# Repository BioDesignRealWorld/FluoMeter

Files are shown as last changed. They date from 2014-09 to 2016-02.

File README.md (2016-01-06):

FluoMeter
=========

This repository contains all technical files (CAD drawings, PCB files,
firmware) to reproduce a quantitative fluorescence measurement device. This
device was created by the [BioDesign for the Real-World](http://biodesign.cc)
project to be used together with a bio-reporter for arsenic or other heavy
metal detection.

* [Chronology and principle of the device](http://wiki.biodesign.cc/wiki/Chronology_of_the_prototypes)
* [Build the FluoMeter](http://wiki.biodesign.cc/wiki/Arsenic-Prototype-4-0)
* [BioDesign wiki](http://wiki.biodesign.cc)
* [BioDesign blog](http://biodesign.cc)
* [Arsenic biosensors literature](http://www.unil.ch/arsenicsensors/en/home/menuguid/literature.html)

What is the BioDesign for the Real-World project ?
--------------------------------------------------

BIO-DESIGN for the REAL WORLD is a transdisciplinary and collaborative research
project to define, build, and field-test prototypes that require the
integration of wetware, hardware, and software to visualise and address real
world water problems.



The project is a partnership between (Art)ScienceBLR with design students from
the Srishti School of Art, Design & Technology, (Bangalore, India) the
Lifepatch citizen initiative in art, science and technology (Yogyakarta,
Indonesia), and students at the School of Life Sciences at EPFL (Lausanne,
Switzerland, and housed in Hackuarium). We collaborate closely with
National Centre for Biological Sciences (NCBS, Bangalore India),
and Universitas Gadjah Mada (Yogyakarta, Indonesia).

We follow the open process – CC BY-SA 3.0 and a do-it-yourself (DIY) and do-it-with-others DIWO) approach. Our documentation can be found on the project wiki and we share our code and designs on github. Be sure to check out our videos and links.

BioDesign started as an idea in the hackterialab 2011 in Romainmôtier in Switzerland. We are part of the hackteria network. Check out Hackteria’s wiki page for other DIYBIO projects and designs.

The project was launched with support by the CoDEV SEED grant from EPFL (2.2013-12.2014).





Contributors
------------

* Sachiko Hirosue
* Robin Scheibler
* Emilie Mussard
* Romain Equey
* Jasmina Rubattel
* Nicolas Krischer
* Bastien Orset
* Falco Enzler
* Thomas Vetterli
* Dounia Droubi
* Marie Duc
* Colombine Verzat
* Marie Willemin
* Mathilde Vidal

Collaborators at large
----------------------

* [Lifepatch](http://lifepatch.org/)
* [(Art)ScienceBLR](http://artscienceblr.org/)
* [Lab of environmental and evolutionary microbiology (UNIL)](http://www.unil.ch/dmf/en/home/menuinst/research-units/van-der-meer.html)
* [Microsystems laboratory 4 (EPFL)](http://lmis4.epfl.ch/)

License
-------

(c) 2015 Biodesign for the Real-World

This is an open-source hardware project shared under the CC-BY-SA. You can
modify, remix, reuse and redistribute this work as long as it is under the same
conditions. See the terms of the license below for more details.

<br /><span xmlns:dct="http://purl.org/dc/terms/" property="dct:title">FluoMeter</span> by <a xmlns:cc="http://creativecommons.org/ns#" href="http://biodesign.cc" property="cc:attributionName" rel="cc:attributionURL">BioDesign for the Real-World</a> is licensed under a <a rel="license" href="http://creativecommons.org/licenses/by-sa/4.0/">Creative Commons Attribution-ShareAlike 4.0 International License</a>.<br />Based on a work at <a xmlns:dct="http://purl.org/dc/terms/" href="https://github.com/BioDesignRealWorld/FluoMeter" rel="dct:source">https://github.com/BioDesignRealWorld/FluoMeter</a>.

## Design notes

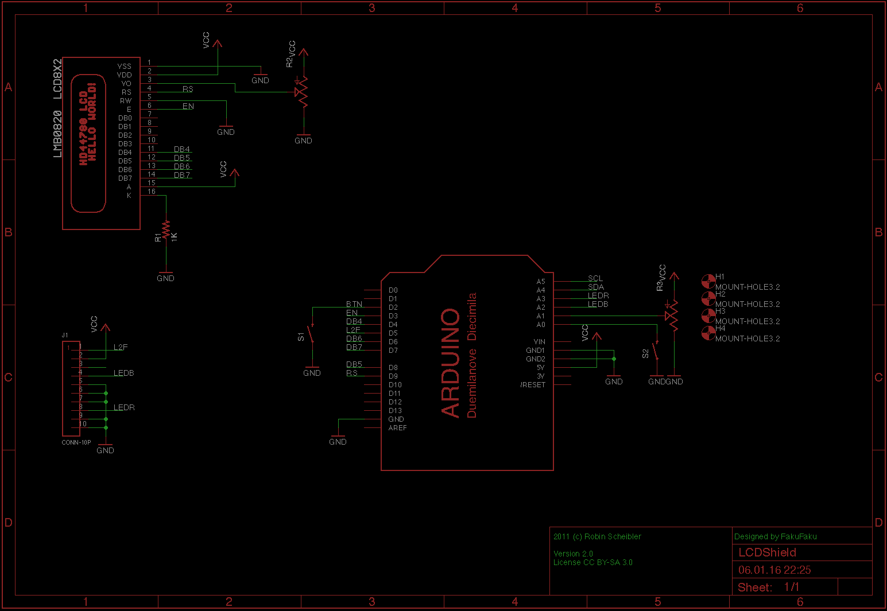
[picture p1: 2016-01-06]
PCB/LCDShield.png

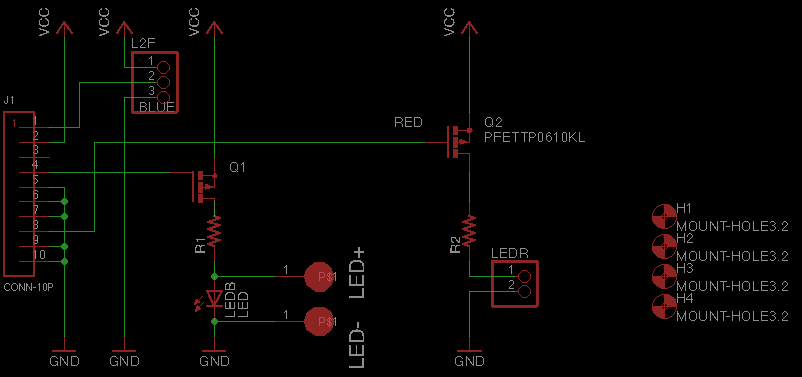
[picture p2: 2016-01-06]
PCB/Proto4_main_board.png

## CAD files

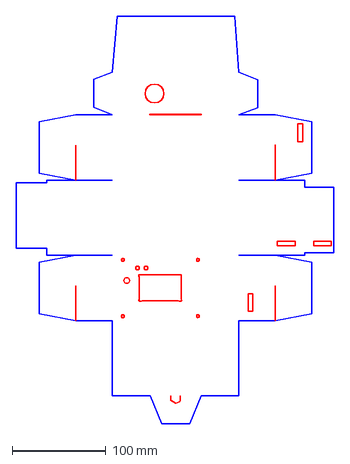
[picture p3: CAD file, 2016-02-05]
CAD/Winter School laser cut box template.dxf
338.6 x 435.0 mm

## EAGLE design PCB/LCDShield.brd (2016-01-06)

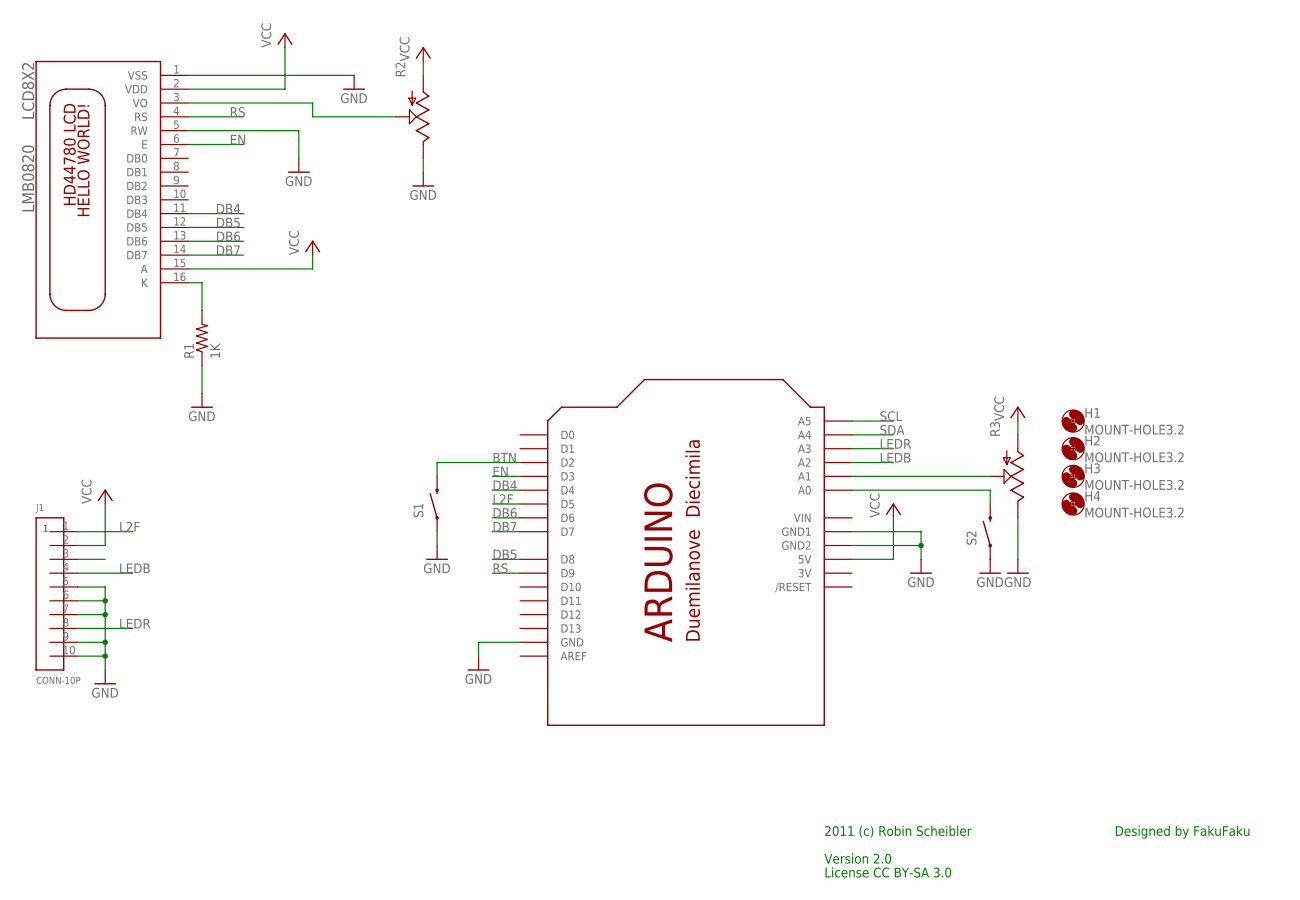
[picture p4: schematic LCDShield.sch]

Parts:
H1, H2, H3, H4: MOUNT-HOLE3.2; 3,2
J1: CONN-10P; MICROMATCH-10P-SMD
LCD8X2: LMB0820
R1: 1K; 0207/10
R2: POTTRIM; TRIM_POT
R3: POT; ALPS_POT
S1, S2: SWITCH-MOMENTARY-2PTH; TACTILE-PTH
SHIELD: ARDUINOSHIELD-PINS; ARDUINO-PINS

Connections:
3V: SHIELD.3V
BTN: S1.3 (2), SHIELD.D2
CON3: J1.3
DB4: LCD8X2.11 (DB4), SHIELD.D4
DB5: LCD8X2.12 (DB5), SHIELD.D8
DB6: LCD8X2.13 (DB6), SHIELD.D6
DB7: LCD8X2.14 (DB7), SHIELD.D7
EN: LCD8X2.6 (E), SHIELD.D3
GND: J1.5, J1.6, J1.7, J1.9, J1.10, LCD8X2.1 (VSS), LCD8X2.5 (RW), R1.1, R2.2 (E), R3.P$1 (E), S1.1, S2.1, SHIELD.GND, SHIELD.GND1, SHIELD.GND2
L2F: J1.1, SHIELD.D5
LEDB: J1.4, SHIELD.A2
LEDR: J1.8, SHIELD.A3
unnamed: LCD8X2.16 (K), R1.2
unnamed: LCD8X2.3 (VO), R2.1 (S)
unnamed: S2.3 (2), SHIELD.A0
unnamed: R3.P$2 (S), SHIELD.A1
RS: LCD8X2.4 (RS), SHIELD.D9
SCL: SHIELD.A5
SDA: SHIELD.A4
VCC: J1.2, LCD8X2.2 (VDD), LCD8X2.15 (A), R2.3 (A), R3.P$3 (A), SHIELD.5V
VIN: SHIELD.VIN

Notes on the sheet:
Version 2.0
License CC BY-SA 3.0
Designed by FakuFaku
2011 (c) Robin Scheibler

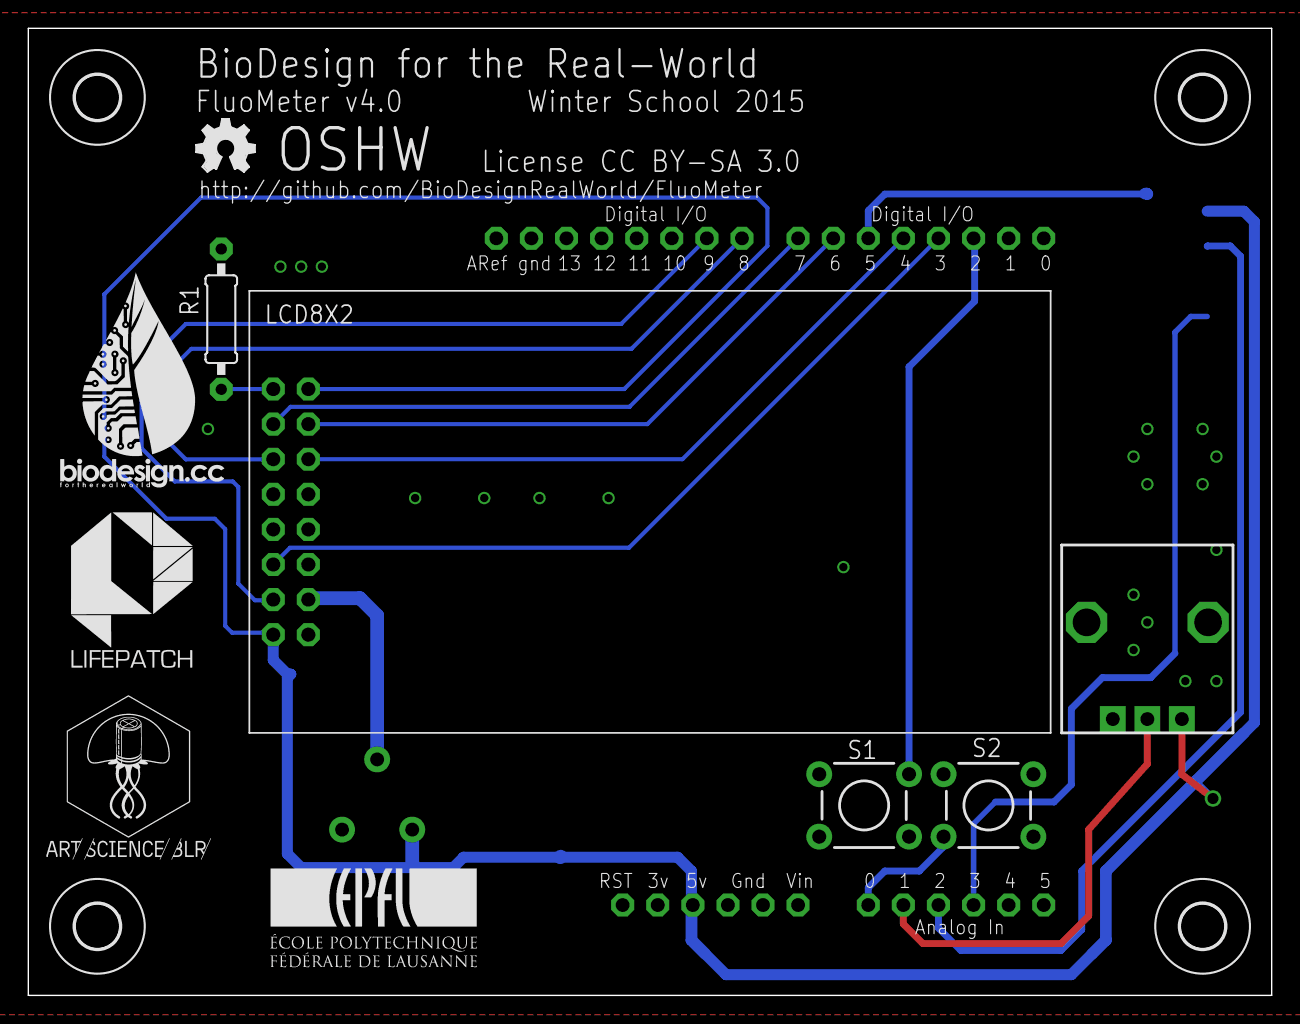
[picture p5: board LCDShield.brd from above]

Board: 2 copper layers, 90.0 x 70.0 mm, 17 parts (1 on the bottom side), 16 nets.

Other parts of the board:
U$1: BIODESIGN
U$4: OSHW_FILLX150_NOTEXT
U$5: LIFEPATCH
U$6: ARTSCIENCEBLR
U$7: EPFL_LOGO_15MM

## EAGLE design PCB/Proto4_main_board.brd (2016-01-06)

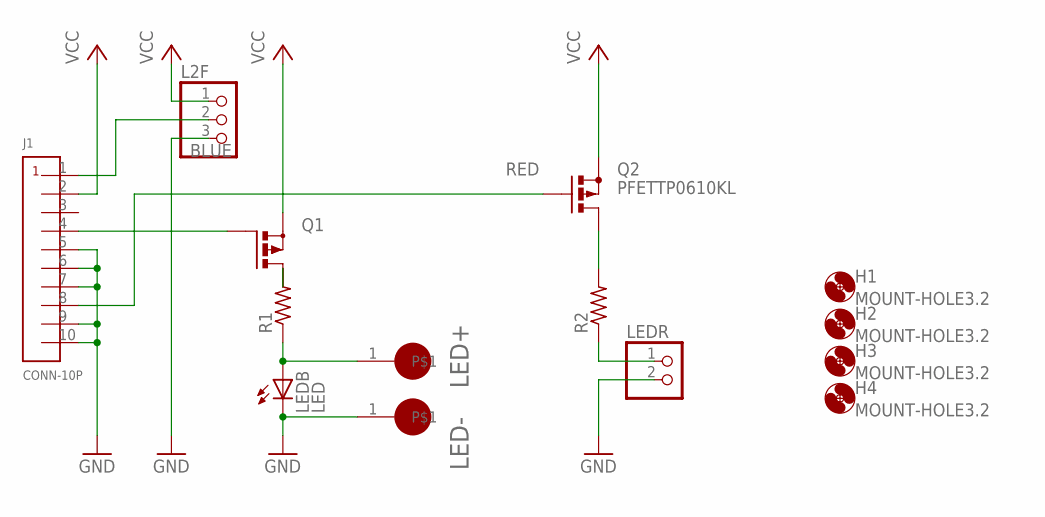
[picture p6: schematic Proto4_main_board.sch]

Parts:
H1, H2, H3, H4: MOUNT-HOLE3.2; 3,2
J1: CONN-10P; MICROMATCH-10P-SMD
L2F: PINHD-1X3/90; 1X03/90
LED+: TP; LARGE_PAD
LED-: TP; LARGE_PAD
LEDB: LED; CREE-XP-E2
LEDR: PINHD-1X2/90; 1X02/90
Q1: PMOSFET_PTO220BH; TO220BH
Q2: PFETTP0610KL; TO92-OVAL
R1: R-US_0414/15; 0414/15
R2: R-US_0309/12; 0309/12

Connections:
BLUE: J1.4, Q1.G
GND: J1.5, J1.6, J1.7, J1.9, J1.10, L2F.3, LED-.1, LEDB.2 (C), LEDR.2
unnamed: Q1.D, R1.2
unnamed: LED+.1, LEDB.1 (A), R1.1
unnamed: Q2.3 (D), R2.2
unnamed: LEDR.1, R2.1
unnamed: J1.1, L2F.2
RED: J1.8, Q2.2 (G)
VCC: J1.2, L2F.1, Q1.S, Q2.1 (S)

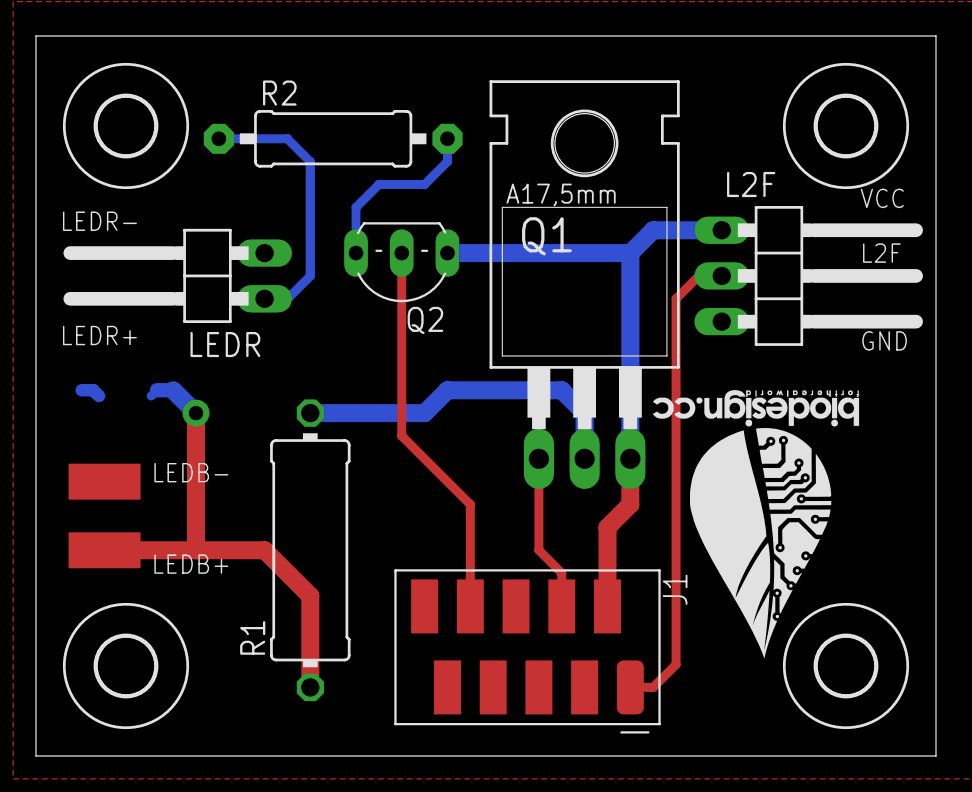
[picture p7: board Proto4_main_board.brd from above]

Board: 2 copper layers, 50.0 x 40.0 mm, 15 parts (1 on the bottom side), 9 nets.

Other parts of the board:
U$1: BIODESIGN-LOGO

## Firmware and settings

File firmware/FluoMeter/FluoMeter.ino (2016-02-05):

#include <math.h>
#include <stdlib.h>  
#include <LiquidCrystal.h>   
#include "Counter.h"

#define TIMER_BLUE 30000    // Time (in milliseconds) of measurement with the blue light for GFP fluorescence quantification
#define TIMER_RED 500  // time (ms) for the measurement of turbidity
#define TIMER_WAIT 150 //time between each intermediary count

#define LED_ON LOW
#define LED_OFF HIGH

#define VERSION "Prototype v4.0"

//define the pin's used 
int blue_led = A2;
int red_led = A3;
int pinCounter = 5;

int button1 = 2;
int button1_int = 0;

// state variables
enum State { NIL, IDLE, COUNT_BLUE, COUNT_RED, COUNT_NOISE };
State state = NIL;

// Counter functions, we have one separate counter for each state of the system.
HardwareCounter hwc(pinCounter, TIMER_BLUE);

// Associate digital pins with the LCD
// Arguments: RS, EN, D4, D5, D6, D7
LiquidCrystal lcd(9, 3, 4, 8, 6, 7);


void button_pressed()
{
  // here we start the counting process
  if (state == IDLE)
  {
    state = COUNT_BLUE;
    lcd.clear();
    lcd.print("Taking");
    lcd.setCursor(0,1);
    lcd.print("measure.");
    Serial.println("Start BLUE.");
    hwc.set_delay(TIMER_BLUE);
    digitalWrite(blue_led, LED_ON);
    hwc.start();
  }
}

void setup()
{
  
  Serial.begin(9600); // Prepare the serial port
  Serial.println(VERSION);
  
  pinMode(blue_led, OUTPUT);
  digitalWrite(blue_led, LED_OFF);
  pinMode(red_led, OUTPUT);
  digitalWrite(red_led, LED_OFF);

  // Prepare the button
  pinMode(button1, INPUT);
  digitalWrite(button1, HIGH);
  attachInterrupt(button1_int, button_pressed, FALLING);

  state = IDLE;

  // LCD start
  lcd.begin(8,2);
  lcd.print("BioDRW");
  lcd.setCursor(0,1);
  lcd.print("HeLLo!");

}

void loop()
{
  
  long count;
  
  if (state != IDLE)
  {
    if (hwc.available())
    {
      switch (state)
      {
        
        case COUNT_BLUE:
          count = hwc.count();
          digitalWrite(blue_led, LED_OFF);
          Serial.print("Fluorescence count: ");
          Serial.println(count);
          lcd.clear();
          lcd.print("B");
          lcd.print(count);
          
          delay(TIMER_WAIT);
          
          // go to next state
          state = COUNT_RED;
          Serial.println("Start RED.");
          hwc.set_delay(TIMER_RED);
          digitalWrite(red_led, LED_ON);
          hwc.start();
          break;
        
        case COUNT_RED:
          count = hwc.count();
          digitalWrite(red_led, LED_OFF);
          Serial.print("Turbidity count: ");
          Serial.println(count);

          lcd.setCursor(0,1);
          lcd.print("R");
          lcd.print(count);
          
          // go to next state
          Serial.println("Finished my job. Go to IDLE.");
          state = IDLE;
          break;
        
        case COUNT_NOISE:
        
          break;
        
        default:
          break;
      }
    }
  }
 
}

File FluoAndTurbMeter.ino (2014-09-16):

#include <math.h>
#include <stdlib.h> 
#include <LiquidCrystal.h>   
#include "Counter.h"

#define TIMER_LENGTH 30000   // Time (in milliseconds) of measurement with the blue light for GFP fluorescence quantification
#define TIMER_LENGTH2 300    // Time (in milliseconds) of measurement with the red light for turbidity quantification
#define AVG_LEN 1
#define PBS 807200.0

// Define functions to control our LEDs
#define led_on() digitalWrite(pinLed, LOW);
#define led_off() digitalWrite(pinLed, HIGH);
#define led_config() pinMode(pinLed, OUTPUT);
#define led2_on() digitalWrite(pinLed2, LOW);
#define led2_off() digitalWrite(pinLed2, HIGH);
#define led2_config() pinMode(pinLed2, OUTPUT);

// Pins used
int pinLed = 13;        // Digital pin 13
int pinLed2 = A2;       // Analog pin 2
int pinCounter = 5;     // Digital pin 5
int button = 3;         // Digital pin 3

// state variables
#define IDLE 0
#define COUNT 1
int state = IDLE;

#define FLUO 0
#define TURB 1
int type = FLUO;        // by default set to FLUO as this is the first measurement we want to do

// Variables used for the button
int buttonstate = 0;
int lastbuttonstate = 0;

// Counter function
HardwareCounter hwc(pinCounter, TIMER_LENGTH);
HardwareCounter hwc2(pinCounter, TIMER_LENGTH2);

// Associate digital pins with the LCD
LiquidCrystal lcd(2, 3, 4, 8, 6, 7);


// Starts the counting for fluorescence
void StartFluo()
{
  if (state == IDLE)
  {
    // State change so we know that we've started counting
    state = COUNT;
    
    // Print that we've started counting
    lcd.begin(8, 2);          // Initialize screen
    lcd.print("Start");
    lcd.setCursor(0, 1);      // Jump to next line
    lcd.print("Counting");
    
    // Turn blue led on
    led_on();
    
    // Start the counter
    hwc.start();
  }  
}


// Starts the counting for turbulence
void StartTurb()
{
  if (state == IDLE)
  {
    // State change so we know that we've started counting
    state = COUNT;
    
    // Print that we've started counting
    lcd.begin(8, 2);          // Initialize screen
    lcd.print("Start2");
    lcd.setCursor(0, 1);      // Jump to next line
    lcd.print("Counting2");
    
    // Turn red led on
    led2_on();
    
    // Start the counter
    hwc2.start();
  }  
}


// Setup of the system
void setup()
{
  // Set up the LCD's number of columns and rows: 
  lcd.begin(8, 2);
  
  // Prepare pin LED
  pinMode(pinLed, OUTPUT);
  led_off();
  
  // Prepare pin LED2
  pinMode(pinLed2, OUTPUT);
  led2_off();
  
  // Prepare the button
  pinMode(A3, INPUT);
  digitalWrite(A3, HIGH); 
}


// Loop function that is continuously executed
void loop()
{
  // Read the state of the button
  buttonstate = digitalRead(A3);
  
  // If the state of the button has changed and that we're in FLUO state, we start the counting for fluorescence
  if (buttonstate != lastbuttonstate && type == FLUO)
  {
    StartFluo();	   
  }
  
  // If fluorescence quantification was done and printed, we next want to quantify turbulance
  if(type == TURB)
  {
    StartTurb();
  }
  
  
  // If the counter for fluorescence has started, we print its result
  if (state == COUNT && hwc.available() && type == FLUO)
  {
    // Get count result
    long count = hwc.count();
    
    // Print result
    lcd.begin(8,2);              // Initialize screen
    lcd.print("Count: ");
    lcd.setCursor(0,1);          // Jump to next line
    lcd.print(count);
    
    // Turn blue led off
    led_off();
    
    // Wait before we start the next counting
    delay(3000);
    
    // Indicate that the next step is turbulance quantification
    state = IDLE;
    type = TURB;
  }  
  
  // If the counter for turbidity has started, we print its result
  if (state == COUNT && hwc2.available() && type == TURB)
  {
    // Get count result
    long count = hwc2.count();
    
    // Print results
    lcd.begin(8,2);              // Initialize screen
    lcd.print("Count2: ");
    lcd.setCursor(0,1);          // Jump to next line
    lcd.print(count);
    
    // Turn red light off
    led2_off();
    
    // Indicate that the next step is fluorescence quantification i.e. set system to initial state
    state = IDLE;
    type = FLUO;
  }   
  
  
  // Save present button state
  lastbuttonstate = buttonstate;
}

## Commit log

2014-09-16 Eagle files for the Fluorescence detector Arduino shield.
    [FluoShield.brd, FluoShield.sch]
2015-03-11 Added the v2.1 PCB design
    [Proto-v2.1 - TO-92.brd, Proto-v2.1 - TO-92.sch]
2016-01-06 Switched to prototype v4.0 for the winter school.
    [FluoShield.brd, FluoShield.sch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]
2016-02-04 Paper Box Lasercut Template
    Winter School 4.0
    [Winter School laser cut box template.dxf]
2016-02-05 Fixed bug that caused the overflow interrupt of the counter to be executed one start, leading to higher count for the first count after start.
2016-02-05 Fixed bug that caused the button interrupt to be executed immediately after power on.
    [FluoMeter.ino]
2016-05-27 Added Arduino mega support for the hardware counter through Timer5 (digital pin 47).
